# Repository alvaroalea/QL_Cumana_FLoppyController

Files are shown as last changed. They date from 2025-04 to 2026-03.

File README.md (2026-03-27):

# Cumana Disk Interface for Sinclair QL

A clone of the Cumana's Floppy Disk Interface for Sinclair QL
(PCB issue 1, ROM version 1.14)

This board has been suessfully tested with ROM 1.16, real floppy disc and gotek.

### The Board

There are two knows version of the ROM, 1.14 and 1.16. unknow diferences between revisiones of ROM.

It use the standar stugart conector, so a plain cable can have up to 4 disk drives, that shall be correctly configured as DS0, DS1, DS2 or DS3.

It use a WD1770 disc controller, but is compatible with WD1772 (you can need to configure start speed), WD1773 is not compatible.

Be aware, when install the transistor, is C,B,E with C near the 7805.

Thanks to Minialler from retrowiki for providing me with a board so I can take pictures and check tracks  that allow me to capture the schema.

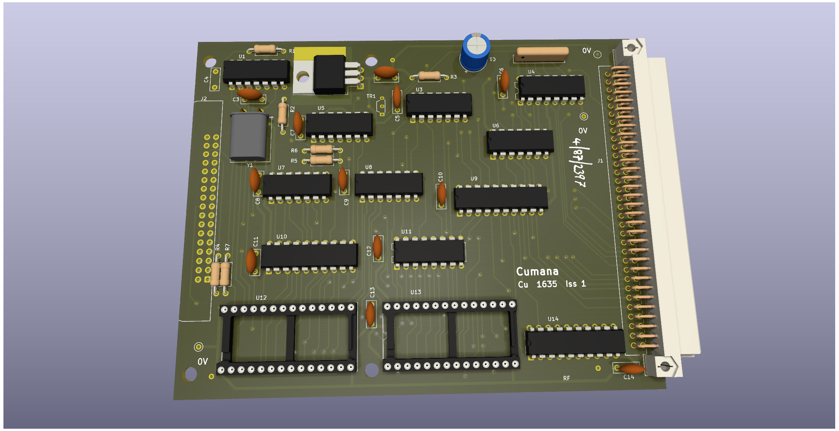
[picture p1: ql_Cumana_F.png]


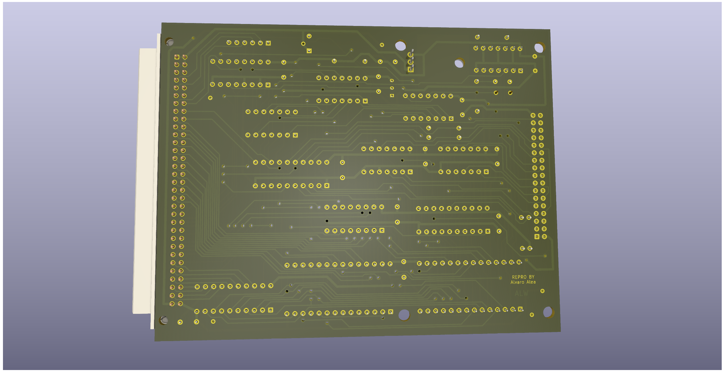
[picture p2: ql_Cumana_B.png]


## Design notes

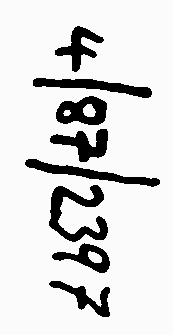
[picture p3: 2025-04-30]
docs/serial.jpg

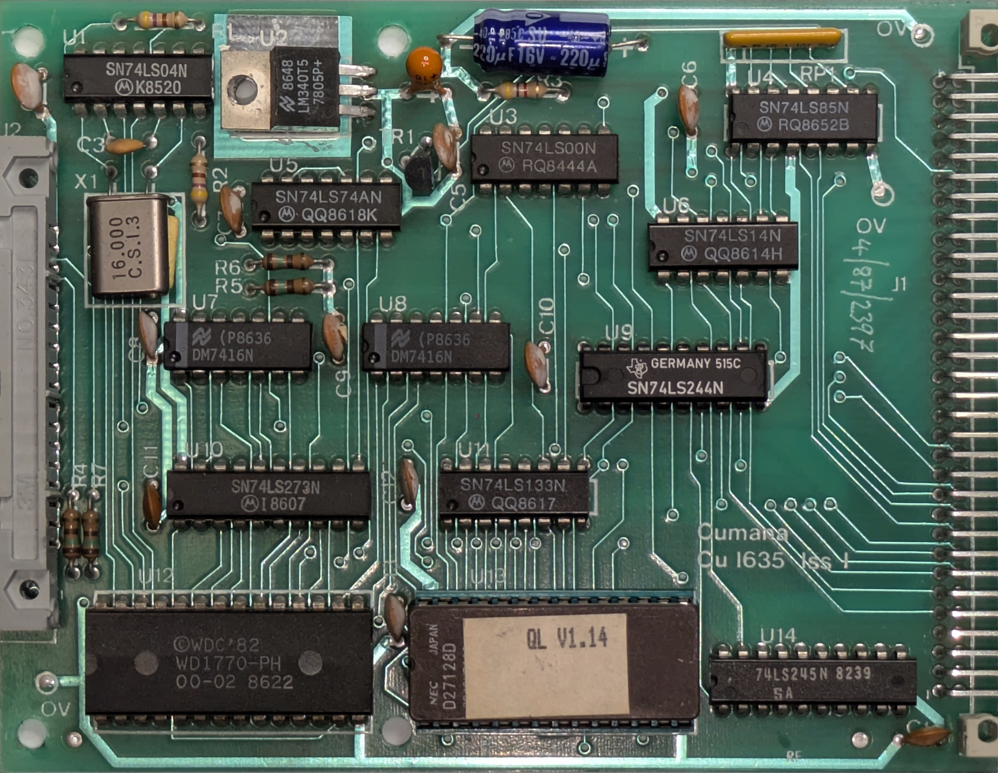
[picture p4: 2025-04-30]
docs/COMP_2.jpg

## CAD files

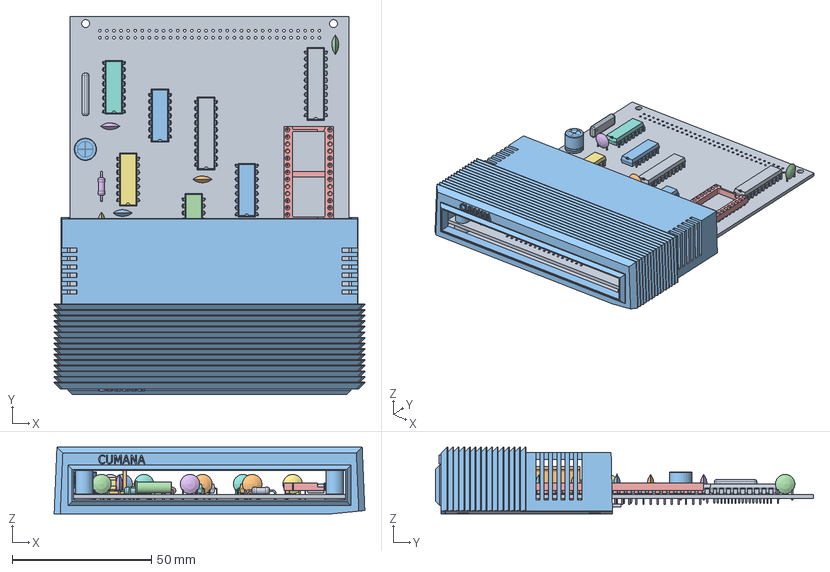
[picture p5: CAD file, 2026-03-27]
3D/carcasa_V3.FCStd
111.4 x 135.6 x 24.0 mm
Lid
Heatsink
Case
DIP-14_W7.62mm017
DIP-14_W7.62mm018
C_Disc_D7.0mm_W2.5mm_P5.00mm038
C_Disc_D7.0mm_W2.5mm_P5.00mm039
DIP-14_W7.62mm019
DIP-20_W7.62mm008
DIP-14_W7.62mm020
DIP-14_W7.62mm021
Crystal_HC18-U_Horizontal001
DIP-28_W15.24mm_Socket005
C_Disc_D7.0mm_W2.5mm_P5.00mm040
C_Disc_D7.0mm_W2.5mm_P5.00mm041
DIP-16_W7.62mm005
R_Axial_DIN0207_L6.3mm_D2.5mm_P10.16mm_Horizontal020
DIP-20_W7.62mm009
CP_Radial_D8.0mm_P5.00mm001
C_Disc_D7.0mm_W2.5mm_P5.00mm042
R_Axial_DIN0207_L6.3mm_D2.5mm_P10.16mm_Horizontal021
R_Axial_DIN0207_L6.3mm_D2.5mm_P10.16mm_Horizontal022
R_Axial_DIN0207_L6.3mm_D2.5mm_P10.16mm_Horizontal023
C_Disc_D7.0mm_W2.5mm_P5.00mm043
R_Array_SIP007
C_Disc_D7.0mm_W2.5mm_P5.00mm044
C_Disc_D7.0mm_W2.5mm_P5.00mm045
C_Disc_D7.0mm_W2.5mm_P5.00mm046
R_Axial_DIN0207_L6.3mm_D2.5mm_P10.16mm_Horizontal024
C_Disc_D7.0mm_W2.5mm_P5.00mm047
DIP-14_W7.62mm022
C_Disc_D7.0mm_W2.5mm_P5.00mm048
DIP-20_W7.62mm010
C_Disc_D7.0mm_W2.5mm_P5.00mm049
DIP-16_W7.62mm006
C_Disc_D7.0mm_W2.5mm_P5.00mm050
DIP-28_W15.24mm_Socket006
R_Axial_DIN0207_L6.3mm_D2.5mm_P10.16mm_Horizontal025
TO-220-3_Horizontal_TabDown001
R_Axial_DIN0207_L6.3mm_D2.5mm_P10.16mm_Horizontal026
ql_Cumana_PCB001

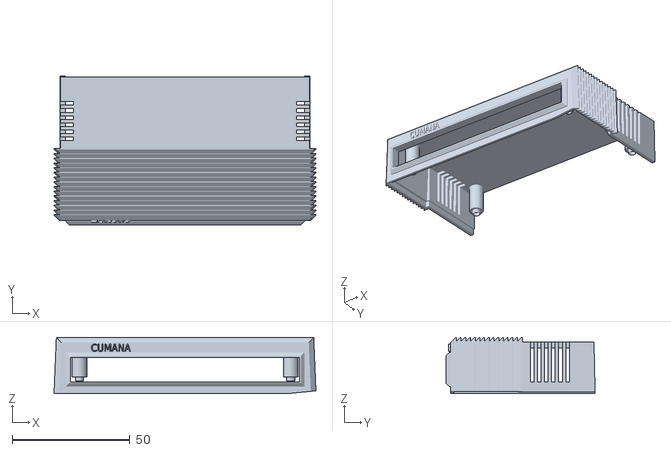
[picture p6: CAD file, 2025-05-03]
3D/case.stl
111.4 x 63.5 x 24.0

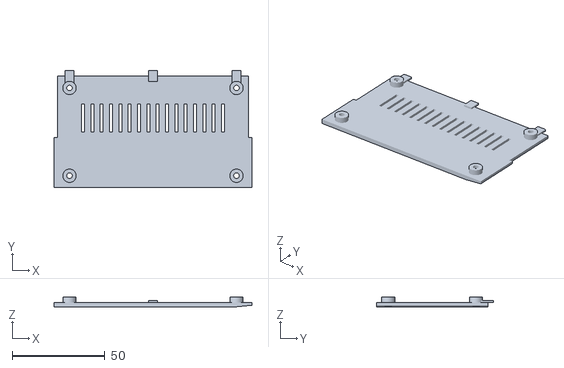
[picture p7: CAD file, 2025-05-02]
3D/lid.stl
106.6 x 63.0 x 5.50

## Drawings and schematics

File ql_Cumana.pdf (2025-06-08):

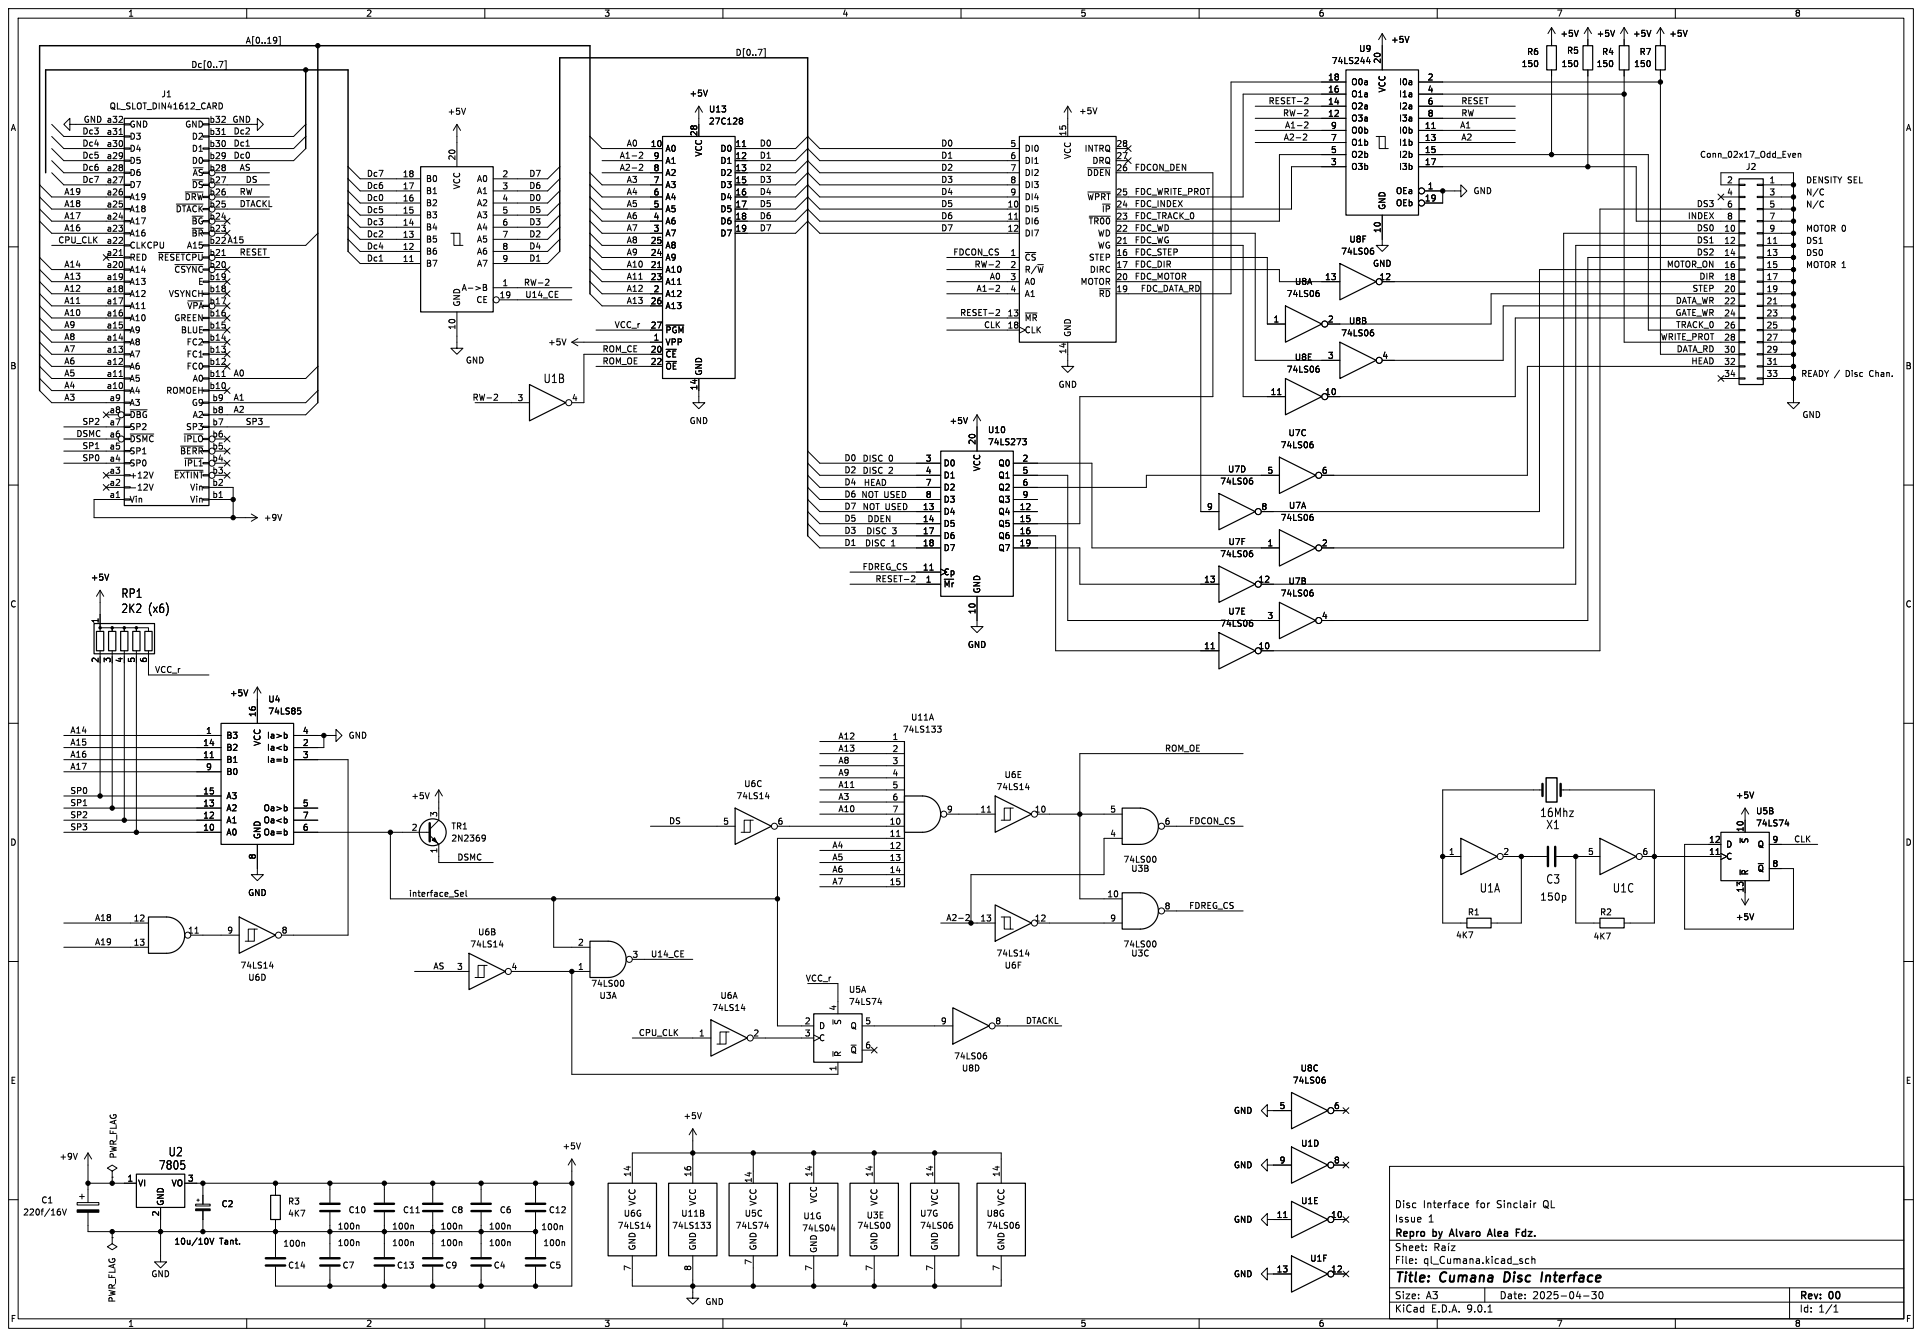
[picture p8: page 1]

INTRQ 28 DRQ 27 ~{DDEN}26 ~{WPRT}25 ~{IP}24 ~{TR00}23 WD 22 WG 21 STEP 16 DIRC 17 MOTOR 20 ~{RD}19 GND

Id: 1/1 Title: Cumana Disc Interface

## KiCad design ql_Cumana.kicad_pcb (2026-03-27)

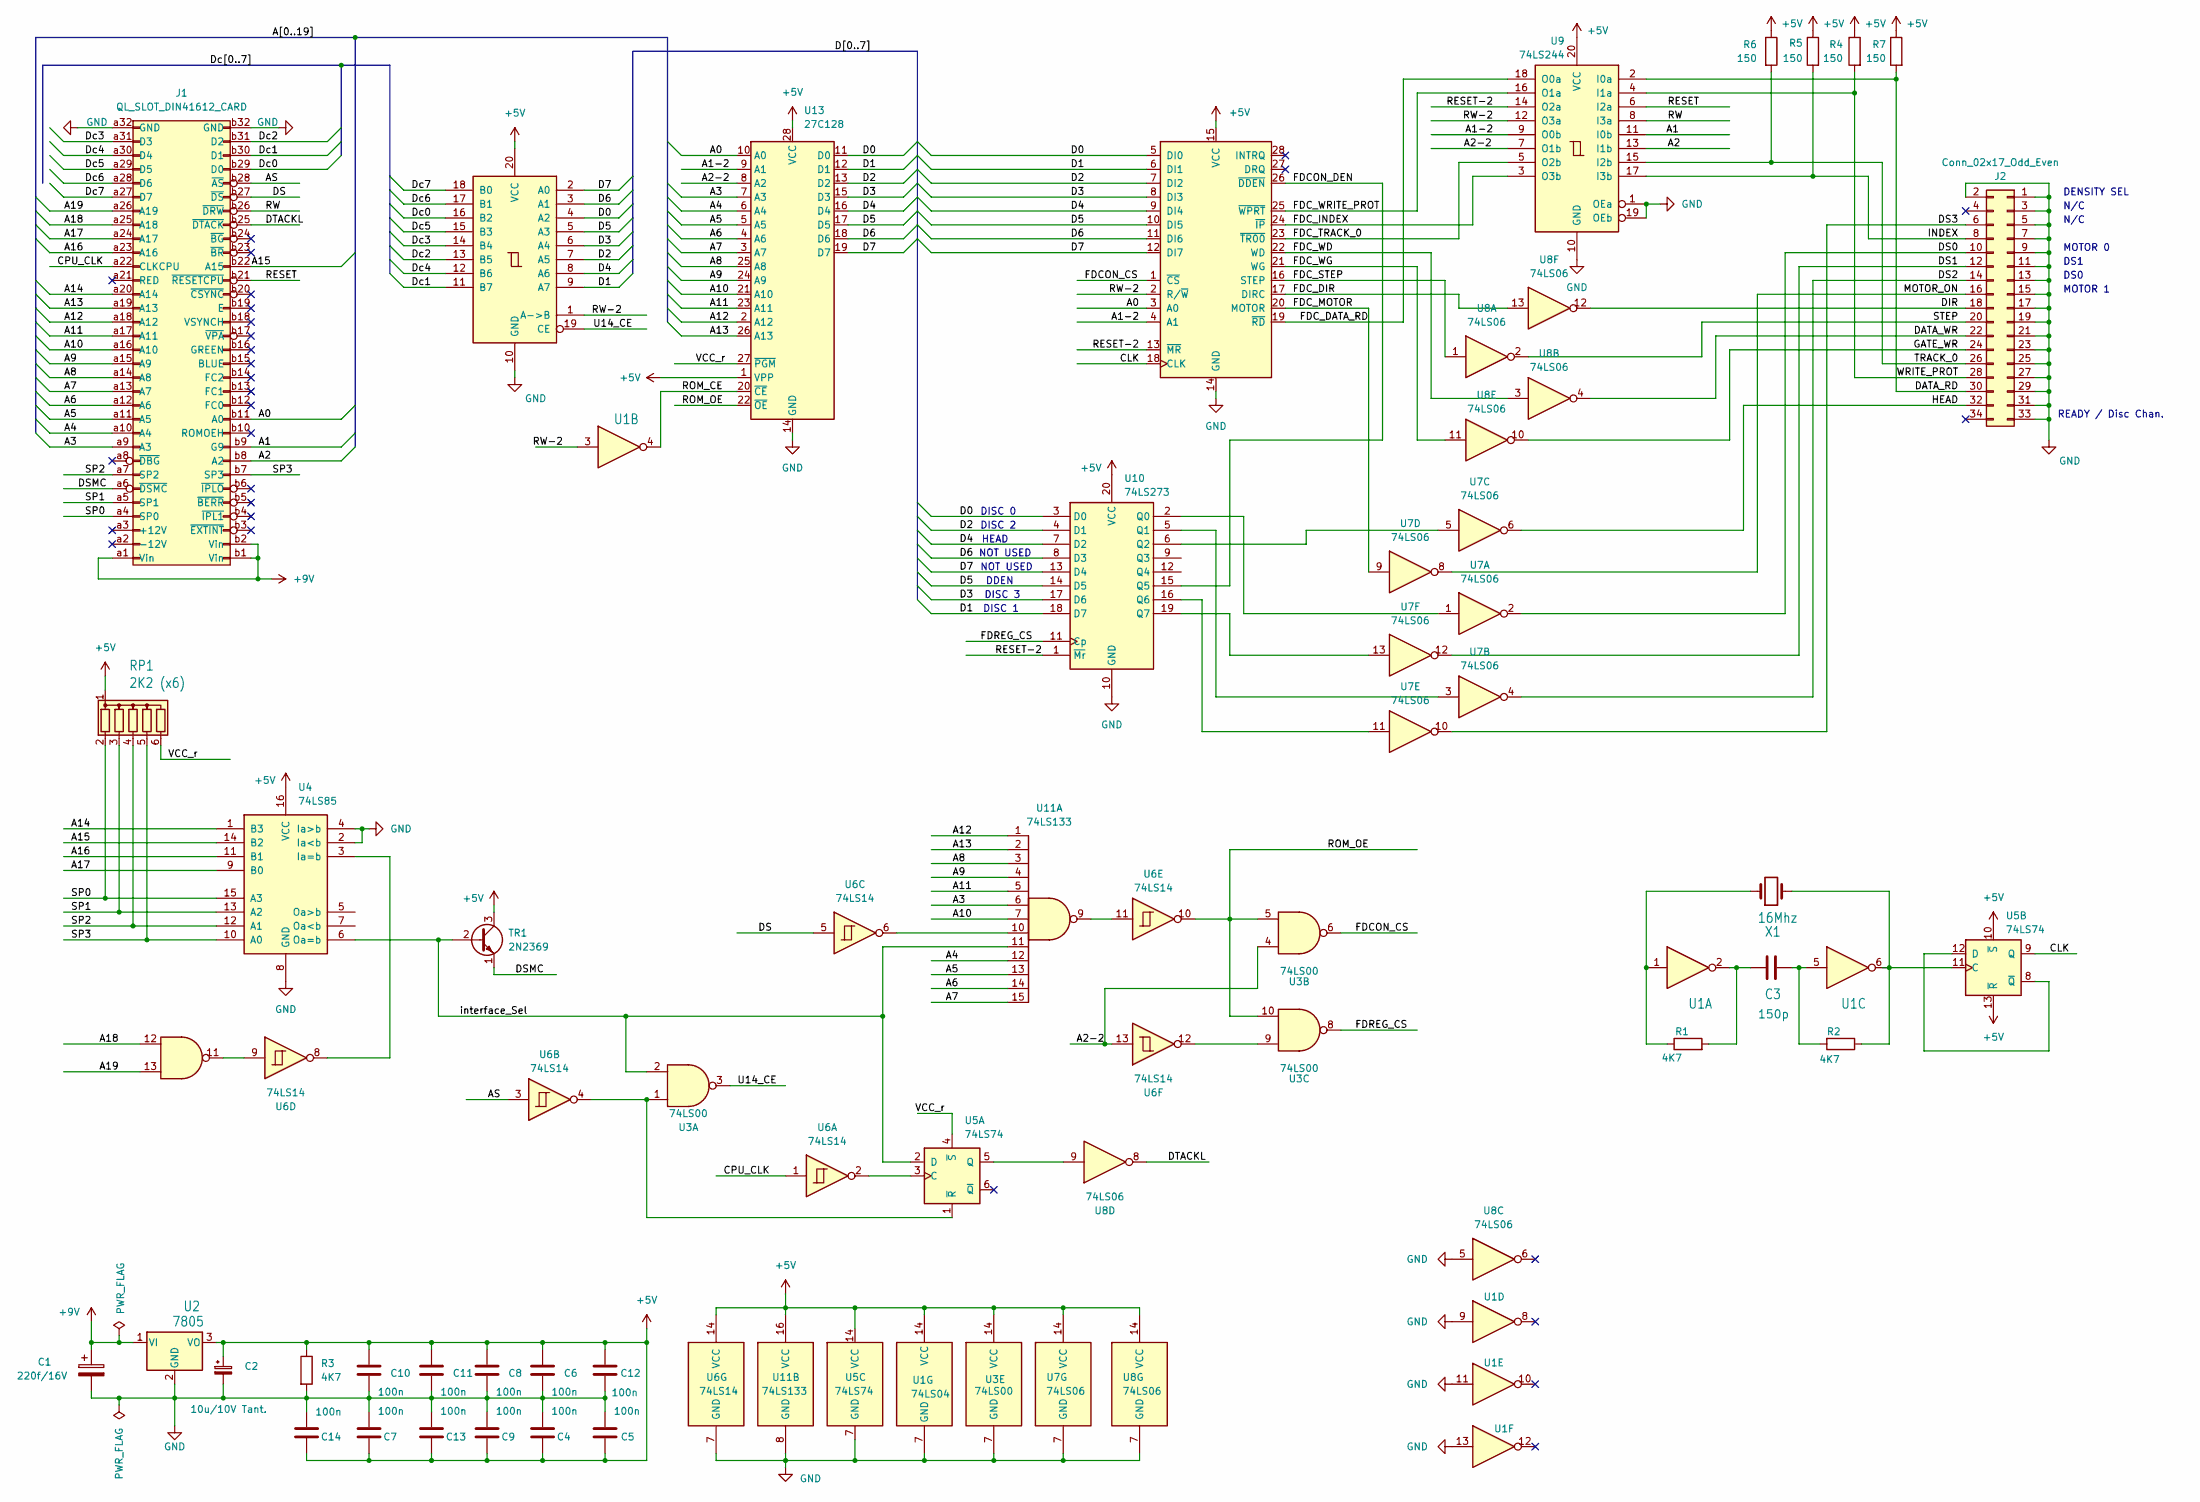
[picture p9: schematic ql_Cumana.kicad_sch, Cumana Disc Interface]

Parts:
C1: 220f/16V; CP_Radial_D8.0mm_P5.00mm
C2: 10u/10V Tant.; C_Disc_D7.0mm_W2.5mm_P5.00mm
C3: 150p; C_Disc_D7.0mm_W2.5mm_P5.00mm
C4, C5, C6, C7, C8, C9, C10, C11, C12, C13, C14: 100n; C_Disc_D7.0mm_W2.5mm_P5.00mm
J1: QL_SLOT_DIN41612_CARD; DIN41612_B_2x32_Female_Horizontal_THT
J2: Conn_02x17_Odd_Even; IDC-Header_2x17_P2.54mm_Latch_Horizontal
R1, R2, R3: 4K7; R_Axial_DIN0207_L6.3mm_D2.5mm_P10.16mm_Horizontal
R4, R5, R6, R7: 150; R_Axial_DIN0207_L6.3mm_D2.5mm_P10.16mm_Horizontal
RP1: 2K2 (x6); R_Array_SIP6
TR1: 2N2369; TO-92S_Wide
U1: 74LS04; DIP-14_W7.62mm
U2: 7805; TO-220-3_Horizontal_TabDown
U3: 74LS00; DIP-14_W7.62mm
U4: 74LS85; DIP-16_W7.62mm
U5: 74LS74; DIP-14_W7.62mm
U6: 74LS14; DIP-14_W7.62mm
U7, U8: 74LS06; DIP-14_W7.62mm
U9: 74LS244; DIP-20_W7.62mm
U10: 74LS273; DIP-20_W7.62mm
U11: 74LS133; DIP-16_W7.62mm
U12: FDC_WD1770; DIP-28_W15.24mm_Socket
U13: 27C128; DIP-28_W15.24mm_Socket
U14: 74LS245; DIP-20_W7.62mm
X1: 16Mhz; Crystal_HC18-U_Horizontal

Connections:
+5V: C2.1, C4.1, C5.1, C6.1, C7.1, C8.1, C9.1, C10.1, C11.1, C12.1, C13.1, C14.1, R3.1, R4.1, R5.1, R6.1, R7.1, RP1.1 (common), TR1.3 (C), U1.14 (VCC), U2.3 (VO), U3.14 (VCC), U4.16 (VCC), U5.10 (~S), U5.13 (~R), U5.14 (VCC), U6.14 (VCC), U7.14 (VCC), U8.14 (VCC), U9.20 (VCC), U10.20 (VCC), U11.16 (VCC), U12.15 (VCC), U13.1 (VPP), U13.28 (VCC), U14.20 (VCC)
+9V: C1.1, J1.a1 (Vin), J1.b1 (Vin), J1.b2 (Vin), U2.1 (VI)
/A0: J1.b11 (A0), U12.3 (A0), U13.10 (A0)
/A1: J1.b9 (G9), U9.11 (I0b)
/A1-2: U9.9 (O0b), U12.4 (A1), U13.9 (A1)
/A2: J1.b8 (A2), U9.13 (I1b)
/A2-2: U3.4, U6.13, U9.7 (O1b), U13.8 (A2)
/A3: J1.a9 (A3), U11.6, U13.7 (A3)
/A4: J1.a10 (A4), U11.12, U13.6 (A4)
/A5: J1.a11 (A5), U11.13, U13.5 (A5)
/A6: J1.a12 (A6), U11.14, U13.4 (A6)
/A7: J1.a13 (A7), U11.15, U13.3 (A7)
/A8: J1.a14 (A8), U11.3, U13.25 (A8)
/A9: J1.a15 (A9), U11.4, U13.24 (A9)
/A10: J1.a16 (A10), U11.7, U13.21 (A10)
/A11: J1.a17 (A11), U11.5, U13.23 (A11)
/A12: J1.a18 (A12), U11.1, U13.2 (A12)
/A13: J1.a19 (A13), U11.2, U13.26 (A13)
/A14: J1.a20 (A14), U4.1 (B3)
/A15: J1.b22 (A15), U4.14 (B2)
/A16: J1.a23 (A16), U4.11 (B1)
/A17: J1.a24 (A17), U4.9 (B0)
/A18: J1.a25 (A18), U3.12
/A19: J1.a26 (A19), U3.13
/AS: J1.b28 (~AS), U6.3
/CLK: U5.9 (Q), U12.18 (CLK)
/CPU_CLK: J1.a22 (CLKCPU), U6.1
/D0: U10.3 (D0), U12.5 (DI0), U13.11 (D0), U14.4 (A2)
/D1: U10.18 (D7), U12.6 (DI1), U13.12 (D1), U14.9 (A7)
/D2: U10.4 (D1), U12.7 (DI2), U13.13 (D2), U14.7 (A5)
/D3: U10.17 (D6), U12.8 (DI3), U13.15 (D3), U14.6 (A4)
/D4: U10.7 (D2), U12.9 (DI4), U13.16 (D4), U14.8 (A6)
/D5: U10.14 (D5), U12.10 (DI5), U13.17 (D5), U14.5 (A3)
/D6: U10.8 (D3), U12.11 (DI6), U13.18 (D6), U14.3 (A1)
/D7: U10.13 (D4), U12.12 (DI7), U13.19 (D7), U14.2 (A0)
/DATA_RD: J2.30, R7.2, U9.2 (I0a)
/DATA_WR: J2.22, U8.4
/DIR: J2.18, U8.12
/DS: J1.b27 (~DS), U6.5
/DS0: J2.10, U7.2
/DS1: J2.12, U7.12
/DS2: J2.14, U7.4
/DS3: J2.6, U7.10
/DSMC: J1.a6 (~DSMC), TR1.1 (E)
/DTACKL: J1.b25 (~DTACK), U8.8
/Dc0: J1.b29 (D0), U14.16 (B2)
/Dc1: J1.b30 (D1), U14.11 (B7)
/Dc2: J1.b31 (D2), U14.13 (B5)
/Dc3: J1.a31 (D3), U14.14 (B4)
/Dc4: J1.a30 (D4), U14.12 (B6)
/Dc5: J1.a29 (D5), U14.15 (B3)
/Dc6: J1.a28 (D6), U14.17 (B1)
/Dc7: J1.a27 (D7), U14.18 (B0)
/FDCON_CS: U3.6, U12.1 (~CS)
/FDCON_DEN: U10.15 (Q5), U12.26 (~DDEN)
/FDC_DATA_RD: U9.18 (O0a), U12.19 (~RD)
/FDC_DIR: U8.13, U12.17 (DIRC)
/FDC_INDEX: U9.3 (O3b), U12.24 (~IP)
/FDC_MOTOR: U7.9, U12.20 (MOTOR)
/FDC_STEP: U8.1, U12.16 (STEP)
/FDC_TRACK_0: U9.5 (O2b), U12.23 (~TR00)
/FDC_WD: U8.3, U12.22 (WD)
/FDC_WG: U8.11, U12.21 (WG)
/FDC_WRITE_PROT: U9.16 (O1a), U12.25 (~WPRT)
/FDREG_CS: U3.8, U10.11 (Cp)
/GATE_WR: J2.24, U8.10
/HEAD: J2.32, U7.6
/INDEX: J2.8, R5.2, U9.17 (I3b)
/MOTOR_ON: J2.16, U7.8
/RESET: J1.b21 (~RESETCPU), U9.6 (I2a)
/RESET-2: U9.14 (O2a), U10.1 (~Mr), U12.13 (~MR)
/ROM_CE: U1.4, U13.20 (~CE)
/ROM_OE: U3.5, U3.10, U6.10, U13.22 (~OE)
/RW: J1.b26 (~DRW), U9.8 (I3a)
/RW-2: U1.3, U9.12 (O3a), U12.2 (R/~W), U14.1 (A->B)
/SP0: J1.a4 (SP0), RP1.2 (R1), U4.15 (A3)
/SP1: J1.a5 (SP1), RP1.3 (R2), U4.13 (A2)
/SP2: J1.a7 (SP2), RP1.4 (R3), U4.12 (A1)
/SP3: J1.b7 (SP3), RP1.5 (R4), U4.10 (A0)
/STEP: J2.20, U8.2
/TRACK_0: J2.26, R6.2, U9.15 (I2b)
/U14_CE: U3.3, U14.19 (CE)
/VCC_r: RP1.6 (R5), U5.4 (~S), U13.27 (~PGM)
/WRITE_PROT: J2.28, R4.2, U9.4 (I1a)
/interface_Sel: TR1.2 (B), U3.2, U4.6 (Oa=b), U5.2 (D), U11.11
GND: C1.2, C2.2, C4.2, C5.2, C6.2, C7.2, C8.2, C9.2, C10.2, C11.2, C12.2, C13.2, C14.2, J1.a32 (GND), J1.b32 (GND), J2.1, J2.2, J2.3, J2.5, J2.7, J2.9, J2.11, J2.13, J2.15, J2.17, J2.19, J2.21, J2.23, J2.25, J2.27, J2.29, J2.31, J2.33, R3.2, U1.7 (GND), U1.9, U1.11, U1.13, U2.2 (GND), U3.7 (GND), U4.2 (Ia<b), U4.4 (Ia>b), U4.8 (GND), U5.7 (GND), U6.7 (GND), U7.7 (GND), U8.5, U8.7 (GND), U9.1 (OEa), U9.10 (GND), U9.19 (OEb), U10.10 (GND), U11.8 (GND), U12.14 (GND), U13.14 (GND), U14.10 (GND)
unnamed: C3.1, R2.2, U1.5
unnamed: C3.2, R1.2, U1.2
unnamed: R1.1, U1.1, X1.1
unnamed: U3.9, U6.12
unnamed: U3.11, U6.9
unnamed: U4.3 (Ia=b), U6.8
unnamed: U5.3 (C), U6.2
unnamed: U5.5 (Q), U8.9
unnamed: U3.1, U5.1 (~R), U6.4
unnamed: R2.1, U1.6, U5.11 (C), X1.2
unnamed: U5.8 (~Q), U5.12 (D)
unnamed: U7.1, U10.2 (Q0)
unnamed: U7.3, U10.5 (Q1)
unnamed: U7.5, U10.6 (Q2)
unnamed: U7.11, U10.16 (Q6)
unnamed: U7.13, U10.19 (Q7)
unnamed: U6.11, U11.9
unnamed: U6.6, U11.10

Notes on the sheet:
NOT USED
MOTOR 0
HEAD
DS0
DS1
READY / Disc Chan.
DDEN
DISC 3
MOTOR 1
N/C
DISC 2
DISC 1
DENSITY SEL
DISC 0

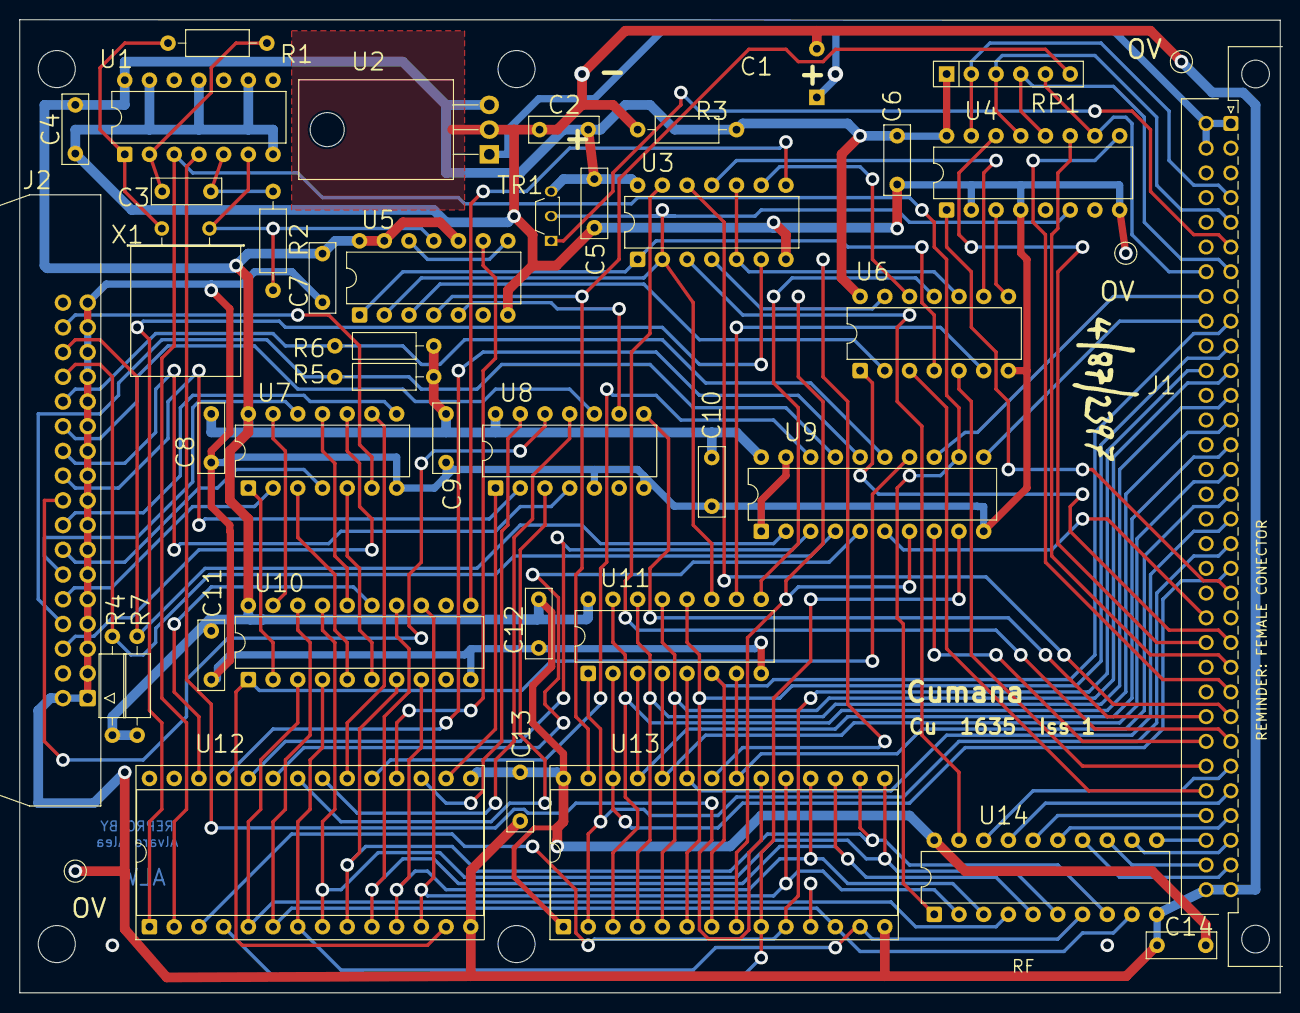
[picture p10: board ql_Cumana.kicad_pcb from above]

Board: 2 copper layers, 129.5 x 100.0 mm, 40 parts (0 on the bottom side), 104 nets.

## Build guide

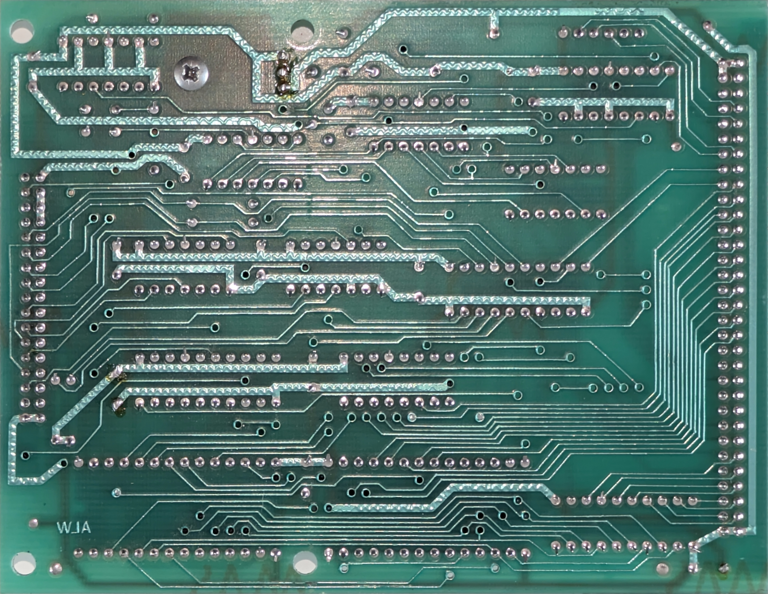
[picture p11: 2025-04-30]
docs/SOLDER_2.jpg

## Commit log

2025-05-02 fix size and add 3D case
    [carcasa_V3.FCStd, case.stl, lid.stl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]
2025-05-03 small size fix
    [carcasa_V3.FCStd, case.stl]
2025-05-08 update silkscreen
    [ql_Cumana.kicad_sch]
2025-06-08 update component values
    [ql_Cumana.kicad_pcb, ql_Cumana.kicad_sch]
